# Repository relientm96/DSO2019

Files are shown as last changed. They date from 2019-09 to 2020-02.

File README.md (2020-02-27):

# DSO2019
Repository of a self-made Digital Oscilloscope Project. Guided by ELEN90053 Electronic System Design subject at the University of Melbourne. 

# Table of Contents
  * [Main Features:](#main-features-)
  * [Subsystems](#subsystems)
  * [System Block Diagram](#system-block-diagram)
  * [PCB Design](#pcb-design)
  * [How it works](#how-it-works)

## Main Features:
- Printed Circuit Board designed in Altium Designer.    
- Atmega16 microcontroller programmed in C.  
- ESP8266 WiFi chip with OLED Screen Display.  
- Web Interface displaying waveform and discrete fourier transform plots, developed using Express.js, HighCharts and Materialize. 

<div style="text-align:center;">
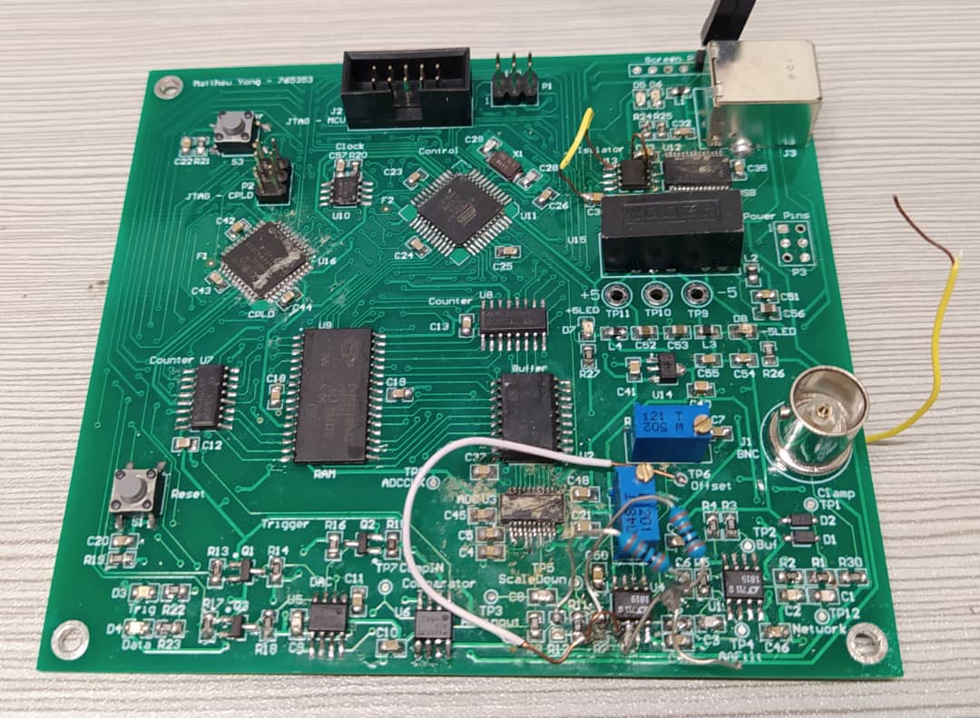
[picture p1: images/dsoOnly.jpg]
    
    <p>Diagram of Finished DSO Board</p>
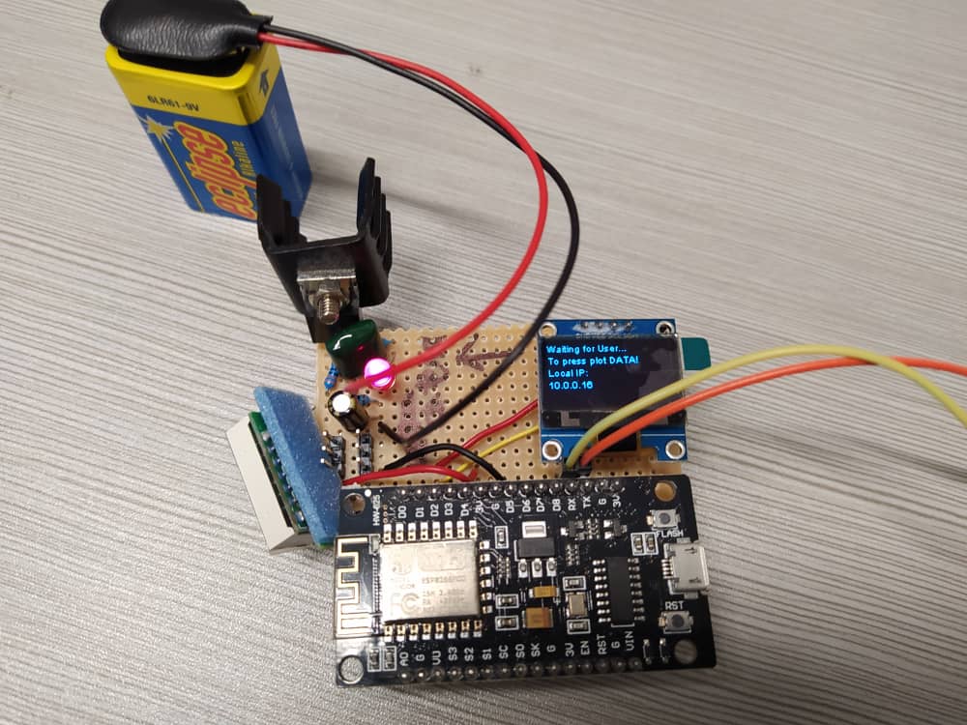
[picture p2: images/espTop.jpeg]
     
    <p>Diagram of IOT ESP8266 Addon with OLED</p>
</div>

## Subsystems
Within the Digital Oscilloscope (DSO), the following subsystems are involved:

1. Front End   
    - BNC (input signal goes here)
    - Clamping Circuit   
    - Scaling Network, Buffer  
    - Anti-Aliasing Filter    
    - Offset Circuit (Level Shifter)
2. Analog to Digital Conversion Circuit      
    - Samples Analog Signals (from BNC Input) 
    - Stores sampled signals into RAM
3. RAM Circuit    
    - Sampled data is stored here  
4. Complex Programmable Logic Device (CPLD)  
    - Group of programmable logic gates that 
    - Handle and route high frequency signals in system. 
5. Input/Output (USB to UART connection) to PC  
    - Connects USB Power to Power circuit
    - Converts USB data to UART
6. Trigger   
    - Comparator circuit that compares the current input signal with the DAC's analog voltage to stabalize output waveform.
7. Power  
    - Provides power supply voltage and current to overall circuit.  
    - USB Voltage to +5V, -5V conversion
    - 5V to 3.3V conversion
8. Control
    - Main brain of the entire system.
    - Micro-controller (ATMEGA-16)  
    - Buttons for Control
9. Counter Circuit 
    - Generates up to 2^16 addresses for samples to be stored in RAM.  

## System Block Diagram
Below is the planned overall block diagram of the entire oscilloscope system.
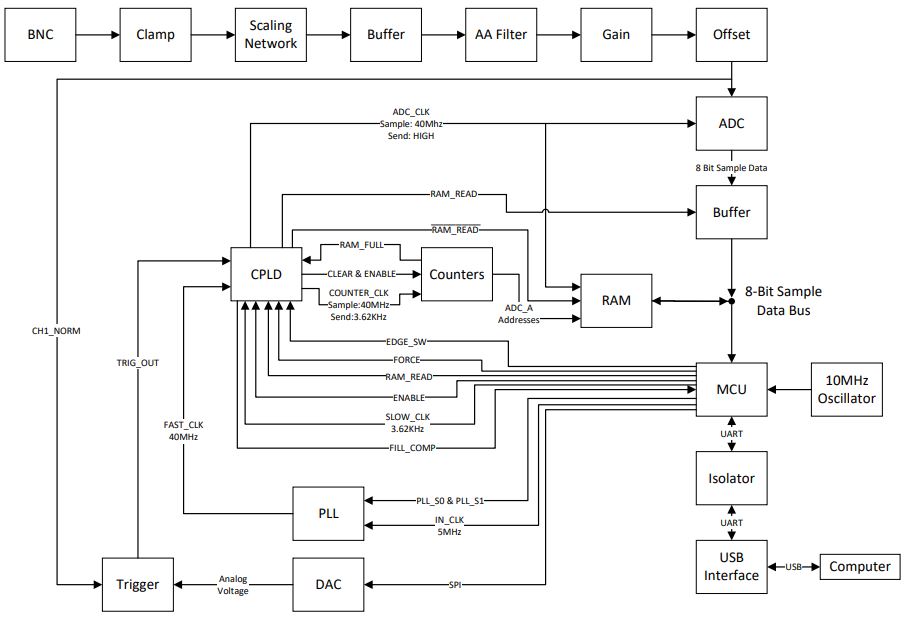
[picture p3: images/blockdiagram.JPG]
Block Diagram


## PCB Design
Generated Top Layer of 2D PCB Design file from Altium Designer.  
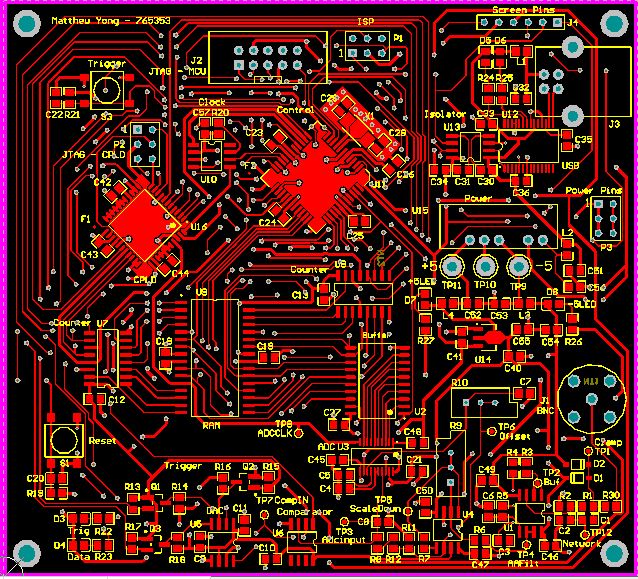
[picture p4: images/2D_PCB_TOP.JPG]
2D PCB
  
Generated Top Layer of 3D PCB Design file from Altium Designer.  
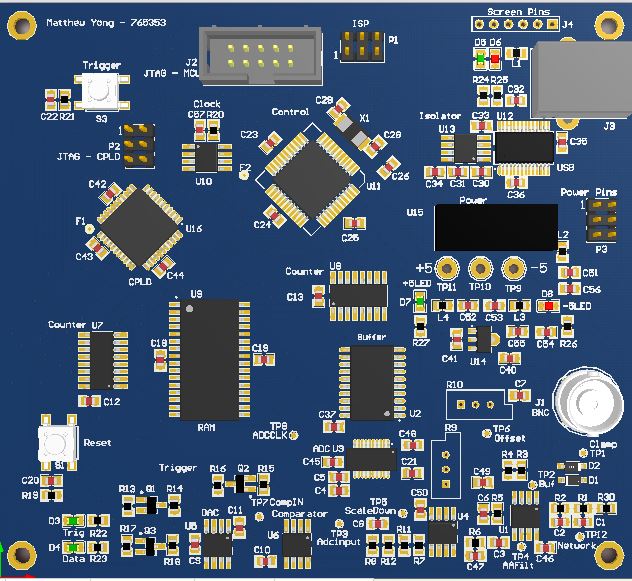
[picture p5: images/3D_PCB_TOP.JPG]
  
Final PCB Design:
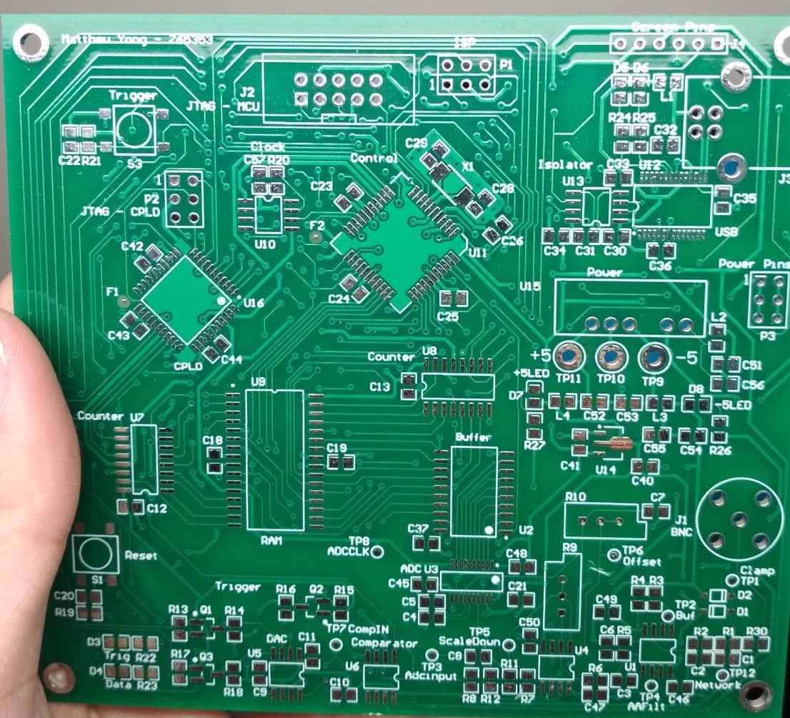
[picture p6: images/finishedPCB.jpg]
  

## How it works
1. Input signal travel from the BNC and is pre-processed for the ADC to sample.
2. Each data is stored onto the ram with up to 2^16 bit addresses generated by 2 8-bit counters.
3. Once ram is full, samples are then sent to the micro-controller and counters reset.
4. After receiving all samples, MCU sends samples to the computer GUI to plot the data using UART.
5. While sending samples, the ESP8266 chip also receives samples and sends plot data to the Web Interface.

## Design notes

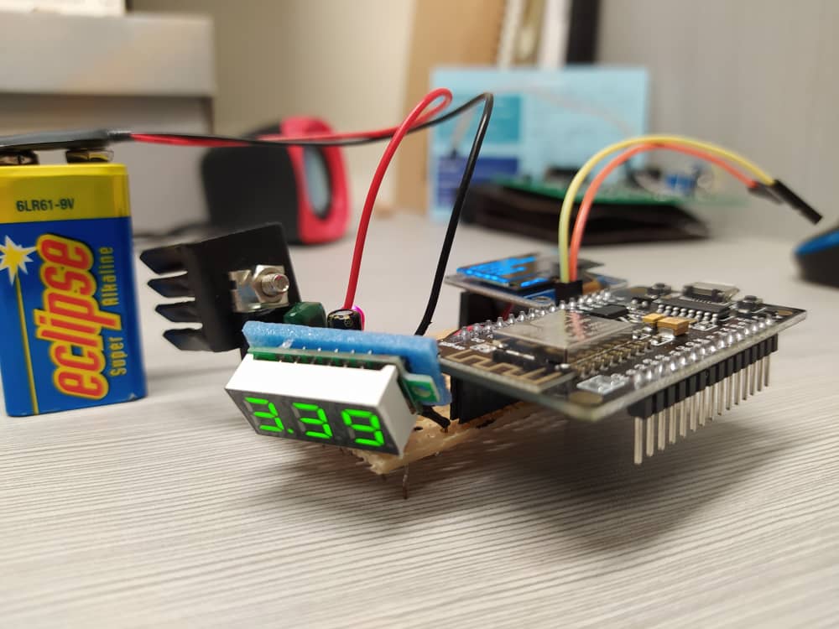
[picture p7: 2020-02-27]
images/espSide.jpeg

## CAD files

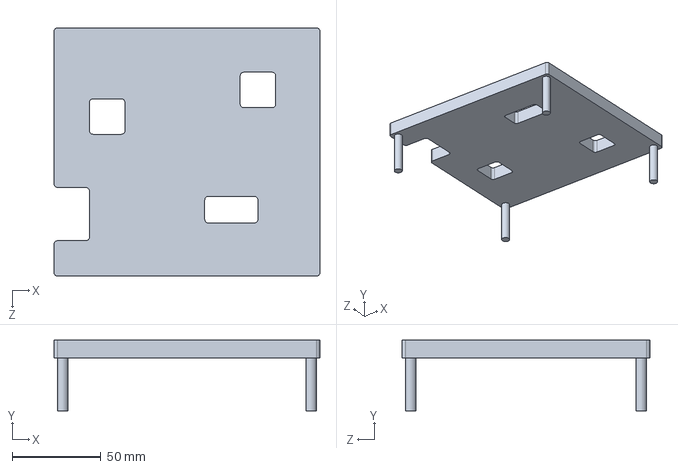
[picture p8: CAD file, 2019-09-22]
3D_Casing/dso_cover.SLDPRT
150.0 x 40.0 x 140.0 mm

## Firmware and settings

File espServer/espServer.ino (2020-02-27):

/*
 * ESP8266 Module for Digital Oscilloscope Project
 * Extension by Matthew Yong
 * Includes a Web Server and an I2C screen communication module
 */

/*----ESP8266 WIFI Modules----*/ 

#include <ESP8266WiFi.h>
#include <WiFiClient.h>
#include <ESP8266WiFiMulti.h>
#include <ESP8266mDNS.h>
#include <ESP8266WebServer.h>

/*----Screen Modules----*/ 
// i2c Library
#include <Wire.h>
#include "SSD1306Wire.h"
#define SCREEN_WIDTH 128 // OLED display width, in pixels
#define SCREEN_HEIGHT 64 // OLED display height, in pixels
// Declaration for an SSD1306 display connected to I2C (SDA, SCL pins)
#define OLED_RESET     4 // Reset pin # (or -1 for i2c)

/*---- Misc Modules ---*/
// String Module
#include <string.h>
// Arduino JSON functions
#include <ArduinoJson.h>

//Constants
#define DATA_LEN 5000
#define DATA_LEN_ARRAY 1000  
//#define WIFI_NAME "china"
//#define WIFI_PASS "bidibadadowop"
#define WIFI_NAME "Belong3D3DC4"
#define WIFI_PASS "tkab4pau6uqx"

//Creating a multiwii class
ESP8266WiFiMulti wifiMulti;
ESP8266WebServer server(80);

//Data buffer
String data;
int dataInt[DATA_LEN] = {0};
// Stores how many samples are used
int counter = 0;
// Index Tracker
int indexTrack = 0;

//Configuration Variables
int numberOfSamples = 0;
int triggerValue    = 0;
int sampleRate      = 0;
int forceTrigger    = 0;
int edgeTrigger     = 0;

//HTTP Handlers
void handleData();
void handleNotFound();
void handleDSOConfigs();
void handleVersion();

// Serial String data
String dsoVersionString = "";
// Config data as a string
String configDataString = "";
// Sends this data to browser
String dataToSendStr = "";

// Temporary Variables to hold temp DSO values
// Stores incoming data as an integer
int incomingData = 0;
// Stores incoming data as a string from DSO
String strDat = "";

// Creating Screen Object
SSD1306Wire display (0x3C, D1, D2);

/*-----------------Print Functions for OLED--------------------*/

// Print Config Data 
void printConfigs() {

  display.setLogBuffer(5, 30);

  String numberOfSamplesStr = "# Samples: ";
  numberOfSamplesStr += String(numberOfSamples, DEC);
  String triggerValueStr = "Trigger Value: ";
  triggerValueStr += String(triggerValue, DEC);
  String sampleRateStr = "Sample Rate: ";
  sampleRateStr += String(sampleRate, DEC);
  String forceTriggerStr = "Force Trigger: ";
  forceTriggerStr += String(forceTrigger, DEC);
  String edgeTriggerStr = "Edge Trigger: ";
  edgeTriggerStr += String(edgeTrigger, DEC);

  String message[] = {
      numberOfSamplesStr,
      triggerValueStr,
      sampleRateStr,
      forceTriggerStr,
      edgeTriggerStr
  };

  for (byte i = 0; i < 5; i++) {
    display.clear();
    // Print to the screen
    display.println(message[i]);
    // Draw it to the internal screen buffer
    display.drawLogBuffer(0, 0);
    // Display it on the screen
    display.display();
    delay(200);
  }
}

// Print any arbitary message onto OLED
void printMessage(String strArray[], int sizeOfArr) {
  
  display.setLogBuffer(5, 30);

  for (byte i = 0; i < sizeOfArr; i++) {
    display.clear();
    // Print to the screen
    display.println(strArray[i]);
    // Draw it to the internal screen buffer
    display.drawLogBuffer(0, 0);
    // Display it on the screen
    display.display();
    delay(500);
  }
}

// Draws Graph in OLED given an array of values
int drawGraph(int dataInt[], int startIndex){

  // Initialize from Origin
  int oldPositionX = 11;
  int oldPositionY = 32;

  // Start Drawing Graph Axes
  display.clear();
  display.drawString(0,0,"+5");
  display.drawString(0,50,"-5");
  display.drawLine(11,5,11,SCREEN_HEIGHT-1);
  display.drawLine(1,SCREEN_HEIGHT/2,SCREEN_WIDTH-1,SCREEN_HEIGHT/2);

  // Obtain length of array 
  int dataLength = sizeof(dataInt)/sizeof(dataInt[0]);

  // Start plotting on OLED
  int m = startIndex;
  int dat = 0;
  for (int i = 12 ; i < SCREEN_WIDTH; i++){
    //dat = 5*sin(0.25*m);
    dat = dataInt[m];
    if (dat >= 0){
      display.drawLine(oldPositionX,oldPositionY,i,32-5*abs(dat));
      oldPositionY = 32 - 5*abs(dat);
    }
    else {
      display.drawLine(oldPositionX,oldPositionY,i,5*abs(dat) + 32);      
      oldPositionY = 5*abs(dat) + 32;
    }
    oldPositionX = i;
    // Increment every nth sample to fit within screen (aliasing)
    //m = m + (int)(dataLength/(SCREEN_WIDTH - 1));   
    // First 127 samples
    m++; 
    display.display();
    delay(10);
  }
  
  display.display();

  return m;
}


void setup(void) {
  Serial.begin(38400);
  delay(10);

  //Initialize Screen
  display.init();
  display.setContrast(255);

  // Flip Screen
  display.flipScreenVertically();

  //Adding Wifi Connection Details
  wifiMulti.addAP(WIFI_NAME, WIFI_PASS);

  String wifiMessage[] = {
      "Welcome Back Master",
      "Trying to connect:",
      "To Wifi..."
  };
  printMessage(wifiMessage, 3);
    
  while (wifiMulti.run() != WL_CONNECTED) { 
    delay(200);
  }  
  
  display.clear();
  
  //Route function handlers to uri paths
  server.on("/", HTTP_GET, handleData);
  server.on("/version", HTTP_GET, handleVersion);
  server.on("/screen", HTTP_GET, handlePlotScreen);
  server.on("/config", HTTP_POST, handleDSOConfigs);
  //serve any request for any unknown URI
  server.onNotFound(handleNotFound);

  //Avoiding CORS Issue
  server.on("/", HTTP_OPTIONS, []() {
    server.sendHeader("Access-Control-Max-Age", "10000");
    server.sendHeader("Access-Control-Allow-Origin", "*");
    server.sendHeader("Access-Control-Allow-Methods", "POST,GET,OPTIONS");
    server.sendHeader("Access-Control-Allow-Headers", "Origin, X-Requested-With, Content-Type, Accept");
    server.send(200, "text/plain", data );
  });

  //Start Server
  server.begin();

  // Print IP and SSID Details
  //printBuffer();
  String message[] = {
      "Welcome Back Master",
      "Connected to:",
      WiFi.SSID(),
      "Local IP:",
      WiFi.localIP().toString(),
  };
  printMessage(message, 5);
  delay(5000);
  display.clear();
}

void loop(void) {
  // Listen for HTTP requests from clients continuosly
  server.handleClient();

  // Print wait message
  String message[] = {
    "Waiting for User...",
    "To press plot DATA!",
    "Local IP:",
    WiFi.localIP().toString()  
  };
  printMessage(message, 4);

  delay(1000);
}

/*-------------------End Point Handlers------------------------*/

void handlePlotScreen(){
   String message[] = {
    "Plotting DSO Data",
    "Onto Screen!!",
  };
  printMessage(message, 2);
  delay(2000);

  server.send(200, "text/plain", "Plotted Onto Screen!");
  
  // Plot data onto OLED
  display.clear();
  indexTrack = 0;
  while(indexTrack < DATA_LEN_ARRAY){
    indexTrack = drawGraph(dataInt, indexTrack);
  }
  display.clear();

}

//Here we read data from DSO and send it to server
void handleData() {
  
  server.sendHeader("Access-Control-Allow-Origin", "*");
  server.sendHeader("Access-Control-Allow-Methods", "POST,GET,OPTIONS");
  server.sendHeader("Access-Control-Allow-Headers", "Origin, X-Requested-With, Content-Type, Accept");

  // Clear Current Buffer
  while( Serial.available() ){
    Serial.read();
  }

  // Ask User to press capture on Computer GUI
  String waitMessage[] = {
  "Reading From DSO",
  "MAXIMUM 5000 Points!",
  "Press Capture on GUI!"
  };
  printMessage(waitMessage,3);

  // We want to get 1000 Data Points
  while (counter < DATA_LEN){
    // We will wait if there is available data
    while(!Serial.available());
    // Read the data in Serial buffer
    incomingData = Serial.read();
    // Read data from DSO
    if( incomingData > 0 ){
      // Add to data array 
      if (counter < DATA_LEN_ARRAY ){
        dataInt[counter] = map(incomingData,0,255,-5,5);
      }
      // Append new data as a string to be sent to browser later
      strDat = String(incomingData);
      dataToSendStr += strDat;
      dataToSendStr += ',';
      counter++;
    }
  }
  
  // Clear current wait message after finish reading 1000 points
  display.clear();
  // Print Successful Message
  String wait2Message[] = {
  "Successfully Read",
  "5000 Points on DSO!",
  "Sending to Browser...",
  "And Plotting!"
  };
  printMessage(wait2Message,4);
    
  // Sends back data to web browser
  server.send(200, "text/plain", dataToSendStr);
  // Reset data points
  dataToSendStr = "";
  display.clear();

/*
  // Plot data onto OLED
  display.clear();
  indexTrack = 0;
  while(indexTrack < DATA_LEN_ARRAY){
    indexTrack = drawGraph(dataInt, indexTrack);
  }
  
  delay(5000);
  display.clear();
*/
  // Reset Counter Variable
  counter = 0;
 
}

//Sends DSO configurations to DSO from web
void handleDSOConfigs() {

  // Parsing
  DynamicJsonDocument doc(147);
  DeserializationError err = deserializeJson(doc, server.arg("plain"));

  if (err){
   // Serial.print("ERROR:");
   // Serial.println(err.c_str());
    server.sendHeader("Access-Control-Allow-Origin", "*");
    server.sendHeader("Access-Control-Allow-Methods", "POST,GET,OPTIONS");
    server.sendHeader("Access-Control-Allow-Headers", "Origin, X-Requested-With, Content-Type, Accept");
    server.send(200, "text/plain", "Changed configurations");
    return;
  }

  // Reading configuration variables from JSON
  numberOfSamples = doc["numberOfSamples"]; 
  triggerValue = doc["triggerValue"]; 
  sampleRate = doc["samplingFreq"]; 
  forceTrigger = doc["forceTrigger"]; 
  edgeTrigger = doc["edgeTrigger"]; 

  // Displaying Results on OLED Screen
  display.clear();
  // Print Config Message Change
  String numberOfSamplesStr = "# Samples: ";
  numberOfSamplesStr += String(numberOfSamples, DEC);
  String triggerValueStr = "Trigger Value: ";
  triggerValueStr += String(triggerValue, DEC);
  String sampleRateStr = "Sample Rate: ";
  sampleRateStr += String(sampleRate, DEC);
  String forceTriggerStr = "Force Trigger: ";
  forceTriggerStr += String(forceTrigger, DEC);
  String edgeTriggerStr = "Edge Trigger: ";
  edgeTriggerStr += String(edgeTrigger, DEC);
  String configMessageStringDisplay[] = {
      numberOfSamplesStr,
      triggerValueStr,
      sampleRateStr,
      forceTriggerStr,
      edgeTriggerStr
  };
  printMessage(configMessageStringDisplay,5);
  delay(4000);

  // Start configuring DSO
  Serial.write('n');
  /*
  // Send values to DSO (Based on DSO Code)
  // Number of Samples Adjustment
  Serial.write('Z');
  Serial.write(numberOfSamples);
  // Trigger Value Change
  Serial.write('t');
  Serial.write(triggerValue);
  */
  // Sampling Frequency Adjustment
  Serial.write('r');
  if( sampleRate == 40 ){
    Serial.write('1'); 
  }
  else if( sampleRate == 20 ){
    Serial.write('2');
  }
  else{
    Serial.write('3');
  }
  // Edge Trigger
  Serial.write('i');
  if(edgeTrigger == 0){
    // Falling Edge
    Serial.write('f');
  }
  else{
    // Rising Edge
    Serial.write('r');
  }

  // Send back config data as a string from dso to see updated change
  /*
  Serial.write('c');
  while (Serial.available()) {
    // get the new byte:
    char inChar = (char)Serial.read();
    // Letter
    if (isalpha(inChar)){
      // add it to the inputString:
      configDataString += inChar; 
    }
    //Numbers
    else {
      int numb = (int)inChar;
      String str = String(numb);
      configDataString += str;
    }
  }
  */

  //Respond to client with new MCU configs
  server.sendHeader("Access-Control-Allow-Origin", "*");
  server.sendHeader("Access-Control-Allow-Methods", "POST,GET,OPTIONS");
  server.sendHeader("Access-Control-Allow-Headers", "Origin, X-Requested-With, Content-Type, Accept");
  server.send(200, "text/plain", configDataString);

  // Reset config string 
  configDataString = "";
}

void handleVersion() {
  server.sendHeader("Access-Control-Allow-Origin", "*");
  server.sendHeader("Access-Control-Allow-Methods", "POST,GET,OPTIONS");
  server.sendHeader("Access-Control-Allow-Headers", "Origin, X-Requested-With, Content-Type, Accept");

  // Set OLED State Display
  display.clear();
  // Print State
  String message[] = {"Reading Version", "From DSO", "Press DSO Version", "on GUI..."};
  printMessage(message, 4);
  delay(300);
  display.clear();

  //Clear Buffer 
  while(Serial.available()>0){
    Serial.read();
  }
  
  // Wait for incoming data from DSO
  while (!Serial.available());
  // Read String Data
  dsoVersionString = Serial.readString();
  
  // Print Finished State
  String message2[] = {"Finished Reading Version: ",dsoVersionString};
  printMessage(message2, 2);
  delay(2000);
  display.clear();

  // Return Version String back to Browser
  server.send(200, "text/plain", dsoVersionString);
  // Reset to empty string
  dsoVersionString = "";
}

//Simple 404 Response
void handleNotFound() {
  server.send(404, "text/plain", "404: Not found");
}

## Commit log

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2019-08-13 Top Level Blocks Added
    [DSO.PcbDoc, DSO.PcbLib, DSO.SCHLIB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]
2019-08-14 Moved AA filter to ADC block
    [DSO.PcbDoc, DSO_ADC.SchDoc, DSO_Front.SchDoc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]
2019-08-14 Added Input Networks
    [DSO_Front.SchDoc, DSO_IO.SchDoc, DSO_Power.SchDoc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]
2019-08-14 Wired top level diagram
    [DSO_Top.SchDoc]
2019-08-15 Removed mf filter
    [DSO_ADC.SchDoc, DSO_Front.SchDoc, DSO_Power.SchDoc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]
2019-08-15 Finish layout of frontend before adc
    [DSO_ADC.SchDoc, DSO_Front.SchDoc, DSO_Top.SchDoc]
2019-08-19 Connected on ADC side
    [DSO_ADC.SchDoc, DSO_Control.SchDoc, DSO_Counters.SchDoc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]
2019-08-19 Draft for ADC section
    [DSO_ADC.SchDoc, DSO_Top.SchDoc]
2019-08-19 Restructured files
    [DSO.PcbDoc, DSO_ADC.SchDoc, DSO_Control.SchDoc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]
2019-08-20 Readjusting blocks
    [DSO_ADC.SchDoc, DSO_Counters.SchDoc, DSO_Top.SchDoc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]
2019-08-20 Adjusted values
    [DSO_ADC.SchDoc, DSO_Counters.SchDoc, DSO_Front.SchDoc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]
2019-09-03 Added test points
    [DSO_ADC.SchDoc, DSO_Control.SchDoc, DSO_Front.SchDoc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]
2019-09-03 Finished clock schematic
    [DSO_ADC.SchDoc, DSO_Clock.SchDoc, DSO_Control.SchDoc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]
2019-09-03 Finished isolator circuit
    [DSO_IO.SchDoc, DSO_Power.SchDoc, DSO_Trig.SchDoc]
2019-09-03 Half done with micro
    [DSO_ADC.SchDoc, DSO_Control.SchDoc, DSO_IO.SchDoc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]
2019-09-03 Reorganized schematics in control
    [DSO_ADC.SchDoc, DSO_Clock.SchDoc, DSO_Control.SchDoc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]
2019-09-03 Saved version
    [DSO.PcbDoc, DSO_Control.SchDoc, DSO_IO.SchDoc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]
2019-09-03 Halfway in nettie
    [DSO.PcbLib, DSO_ADC.SchDoc]
2019-09-03 Finished net tie
    [DSO.SCHLIB]
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2019-09-03 Able to place fiducial and net tie
    [DSO.SCHLIB, DSO_Power.SchDoc]
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2019-09-05 Lableled circuits and cleaned up schematics
    [DSO_ADC.SchDoc, DSO_Clock.SchDoc, DSO_Control.SchDoc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]
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2019-09-05 Added title to pages
    [DSO_Counters.SchDoc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]
2019-09-05 Added more boxes and tidied stuff
    [DSO.PcbLib, DSO_ADC.SchDoc, DSO_Counters.SchDoc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]
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2019-09-05 Adde rx/tx led status
    [DSO_ADC.SchDoc, DSO_Clock.SchDoc, DSO_Control.SchDoc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]
2019-09-05 Compiled and check up to errors known
    [DSO_ADC.SchDoc, DSO_Clock.SchDoc, DSO_Control.SchDoc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]
2019-09-05 Fixed bug in data bus
    [DSO_Control.SchDoc, DSO_RAM.SchDoc, DSO_Top.SchDoc]
2019-09-06 Added new headers for exposing
    [DSO_Control.SchDoc, DSO_IO.SchDoc, DSO_Power.SchDoc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]
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2019-09-06 Checked frontend and adc
    [DSO_ADC.SchDoc, DSO_Clock.SchDoc, DSO_Control.SchDoc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]
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2019-09-06 Updated pullup in pll
    [DSO_Clock.SchDoc]
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2019-09-06 Hysteresis set back to 4mV
    [DSO_Trig.SchDoc]
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2019-09-10 Updated schematic after feedback
    [DSO_IO.SchDoc, DSO_Power.SchDoc]
2019-09-10 Fixed schematic errors, and reimported parts to pcn
    [DSO.PcbDoc, DSO_ADC.SchDoc, DSO_Control.SchDoc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]
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2019-09-10 Saved PCB Before starting
    [DSO.PcbDoc]
2019-09-10 Created pcb hole part
    [DSO.PcbLib]
2019-09-10 Created schematic part for holes, placed onto pcb
    [DSO.PcbDoc, DSO.SCHLIB, DSO_Power.SchDoc]
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2019-09-10 Cleaned up components into sections
    [DSO.PcbDoc, DSO_Front.SchDoc, DSO_Trig.SchDoc]
2019-09-10 Some routing in system sections
    [DSO.PcbDoc, DSO_Front.SchDoc]
2019-09-12 Fixed 2 op amp only problem
    [DSO.PcbDoc, DSO_ADC.SchDoc, DSO_Front.SchDoc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]
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2019-09-12 New upgrade to power
    [DSO.PcbDoc, DSO.SCHLIB, DSO_ADC.SchDoc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]
2019-09-12 Fixed extra decoupling caps on I/O
    [DSO.PcbDoc, DSO_IO.SchDoc]
2019-09-12 Halfwaydone USB Serial Chip
    [DSO.PcbDoc]
2019-09-12 Added rule for USBVCC 20mil track
    [DSO.PcbDoc, DSO_IO.SchDoc]
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2019-09-12 Finishing Touches to I/O
    [DSO.PcbDoc]
2019-09-12 Adjusted LED on I/O
    [DSO.PcbDoc]
2019-09-12 Moved PCB files into Altium Folder
    [DSO.PcbDoc, DSO.PcbLib, DSO.SCHLIB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]
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2019-09-12 Layedout DC-DC and CapsInput
    [DSO.PcbDoc, DSO_Power.SchDoc]
2019-09-12 Added most components from POWER
    [DSO.PcbDoc, DSO_Power.SchDoc]
2019-09-12 Flipped layout to accomodate for USBGND
    [DSO.PcbDoc]
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2019-09-12 Edited DVCC trace for PINs
    [DSO.PcbDoc]
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2019-09-12 Locked Power and USB
    [DSO.PcbDoc]
2019-09-12 Fixed USB layout in I/O
    [DSO.PcbDoc]
2019-09-12 Additional routing for power and I/O
    [DSO.PcbDoc]
2019-09-12 Fixed bug in connection of front end
    [DSO.PcbDoc, DSO_Front.SchDoc]
2019-09-12 Completed frontend up to network
    [DSO.PcbDoc]
2019-09-12 Added space for +/-5 Indicators in Power
    [DSO.PcbDoc]
2019-09-12 Finished Front End, HalfWay ADC
    [DSO.PcbDoc, DSO_ADC.SchDoc, DSO_Front.SchDoc]
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2019-09-12 Added one Decap for OCTAL Buffer
    [DSO.PcbDoc, DSO_ADC.SchDoc]
2019-09-12 Finished up to level shifter
    [DSO.PcbDoc]
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2019-09-13 Trying to route RAM
    [DSO_Control.SchDoc]
2019-09-13 Finished ADC, Starting RAM Placement
    [DSO_Control.SchDoc, DSO_Top.SchDoc]
2019-09-15 Changed pins on MCU
    [DSO_Control.SchDoc]
2019-09-15 Removed extra cap from Control
    [DSO_Control.SchDoc]
2019-09-15 Crystal and Changed to DGND for AV
    [DSO_Control.SchDoc]
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2019-09-15 Finished control except pins
    [DSO_Control.SchDoc]
2019-09-15 Did progress in routing trigger
    [DSO_Trig.SchDoc]
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2019-09-17 Removed extra caps from counter and cpld
    [DSO_Counters.SchDoc, DSO_Power.SchDoc]
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2019-09-18 New Route For CPLD and MCU
    [DSO_Control.SchDoc, DSO_Power.SchDoc]
2019-09-18 3/4 routing ram and counter
    [DSO_Control.SchDoc]
2019-09-19 Routed all bus, ram and address
    [DSO_Control.SchDoc]
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2019-09-19 Saved version after drc
    [DSO_Power.SchDoc, DSO_Template.PrjPCB]
2019-09-19 Created Job Output Files
    [DSO_Template.PrjPCB]
2019-09-20 Edited PCB and new job file released
    [DSO.PcbLib, DSO.SCHLIB, DSO_Power.SchDoc]
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2019-09-22 Added 3D Designed SolidWorks Files
    [dso_cover.SLDPRT]
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
